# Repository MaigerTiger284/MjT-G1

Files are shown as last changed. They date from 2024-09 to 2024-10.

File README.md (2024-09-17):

โปรเจค MjT-G1 คือ เครื่องพิมพ์ 3 มิติ ที่ใช้โครงของ Davinci 1.0A เอามาพัฒนาต่อ ให้ใช้งานได้ดีขึ้น โปรเจดนี้ขึ้นเพื่อเป็นวิทยานิพนธ์เพื่อจบการศึกษมหาวิทยาลัยเทคโนโลยีราชมงคลพระนคร วิทยาเขตพระนครเหนือ

วัตถุประสงค์
- เพื่อศึกษาการทำงานเครื่องพิมพ์ 3 มิติ รุ่น Da Vinci 1.0A, Ender 5+, Anet et4+
- เพื่อศึกษาชุดคำสั่งของโปรแกรม klipper 
- เพื่อออกแบบระบบปฏิบัติการให้กับแท็บเล็ต Microsoft Surface RT ให้สามารถทำงานได้เหมาะสมกับเครื่องพิมพ์ 3 มิติ
- เพื่อออกแบบให้สามารถใช้เส้นพลาสติกของบริษัททั่วไปได้
- เพื่อออกแบบเพิ่มพื้นที่ฐานพิมพ์ให้มากขึ้น
- เพื่อออกแบบให้สามารถควบคุมการทำงานของเครื่องพิมพ์ 3 มิติ ผ่านสมาร์ทโฟน Androids หรือ IOS นอกสถานที่ได้ โดยใช้ระบบ Webserver Fluidd ที่เชื่อมต่อด้วย VPN (Virtual Private Network) ของ Zerotier One

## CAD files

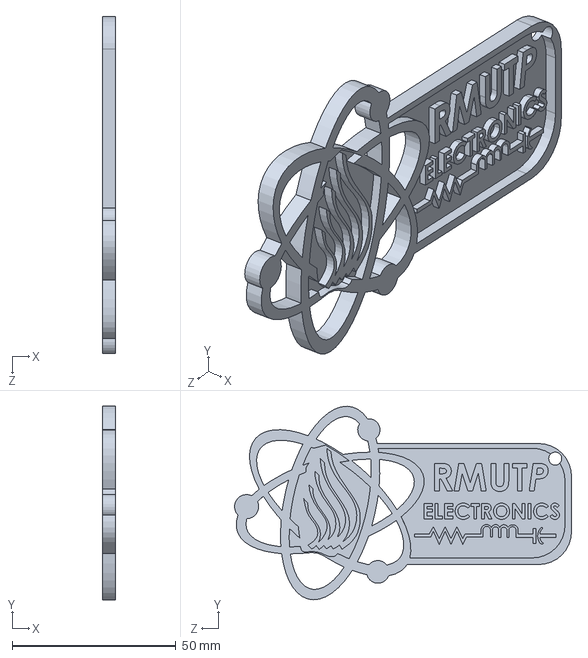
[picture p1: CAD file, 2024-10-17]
MjT-G1 Assembly 1/solidwork assembly part/key v2 EE.SLDPRT
4.00 x 59.2 x 103.0 mm

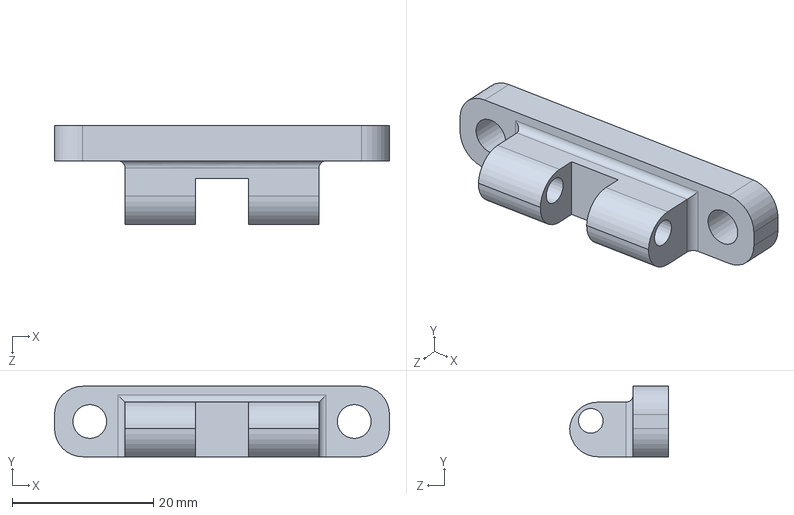
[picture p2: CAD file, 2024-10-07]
MjT-G1 Assembly 1/solidwork assembly part/webcam Stend.SLDPRT
47.5 x 10.0 x 14.0 mm

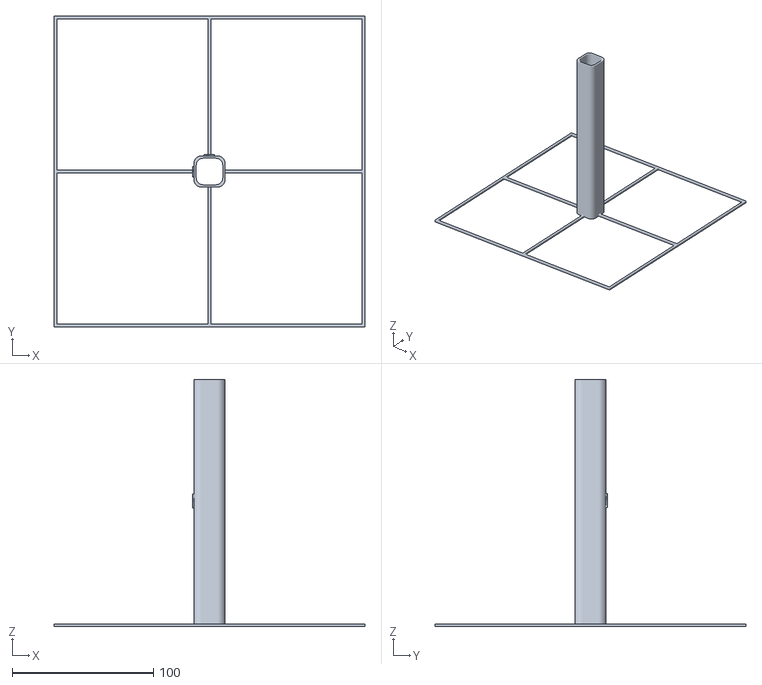
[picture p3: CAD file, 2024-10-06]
MjT-G1 Assembly 1/solidwork assembly part/bedtest 220x220.stl
220.0 x 220.0 x 175.0

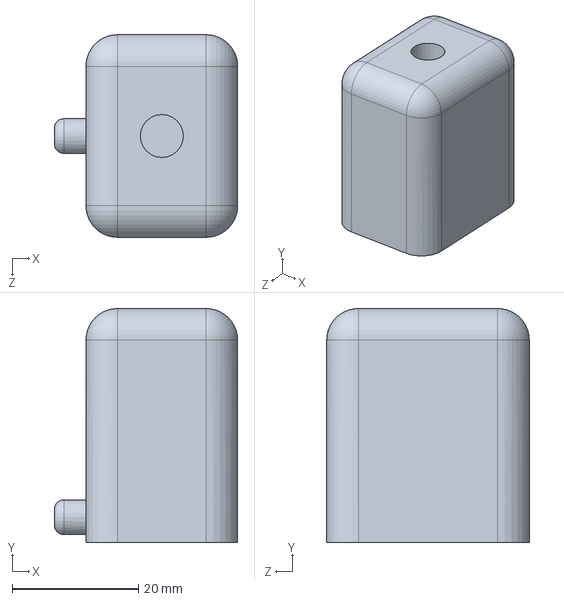
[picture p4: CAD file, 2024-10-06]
MjT-G1 Assembly 1/solidwork assembly part/ypully4.SLDPRT
29.0 x 37.0 x 32.0 mm

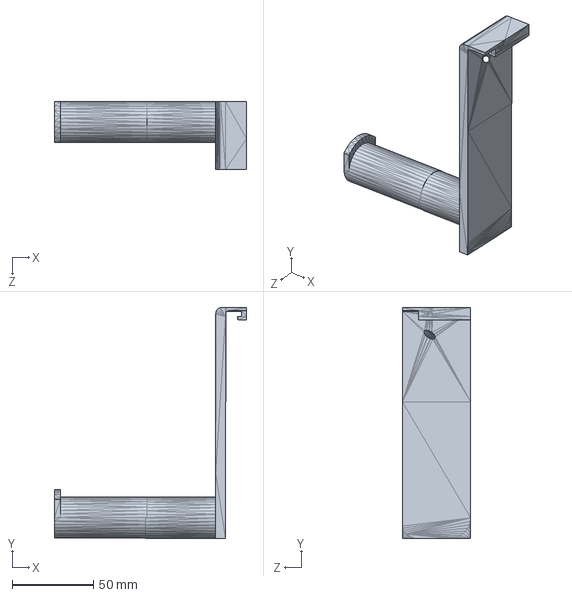
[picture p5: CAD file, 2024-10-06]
MjT-G1 Assembly 1/solidwork assembly part/xyz_davinci_10_pro_rear_spool_mount.SLDPRT
118.2 x 142.0 x 42.0 mm

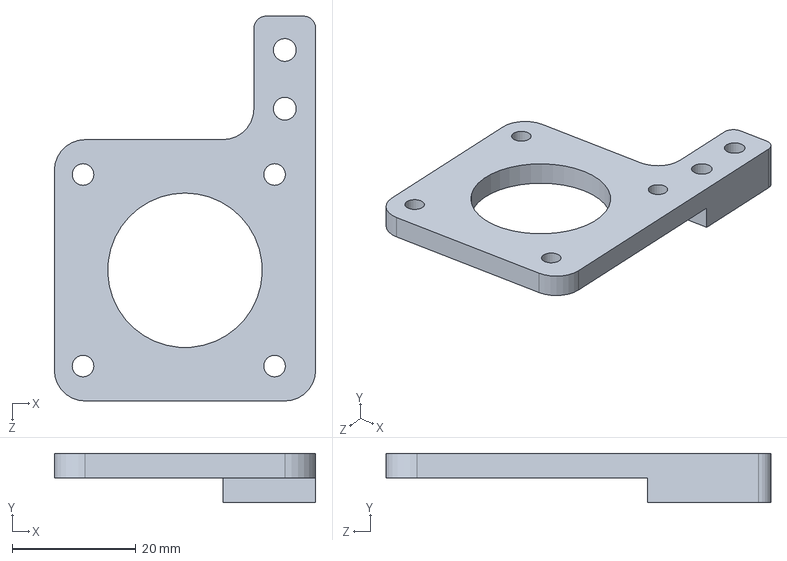
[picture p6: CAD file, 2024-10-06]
MjT-G1 Assembly 1/solidwork assembly part/yendstopand servo.SLDPRT
42.3 x 8.00 x 62.3 mm

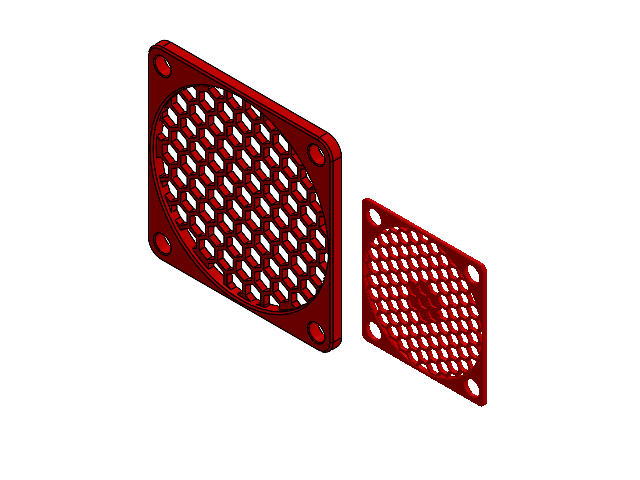
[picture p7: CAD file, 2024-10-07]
MjT-G1 Assembly 1/solidwork assembly part/Fan 40mm and 60mm.SLDASM
Honeycomb Fan Grill (Small Center)
60mm fan guard.step

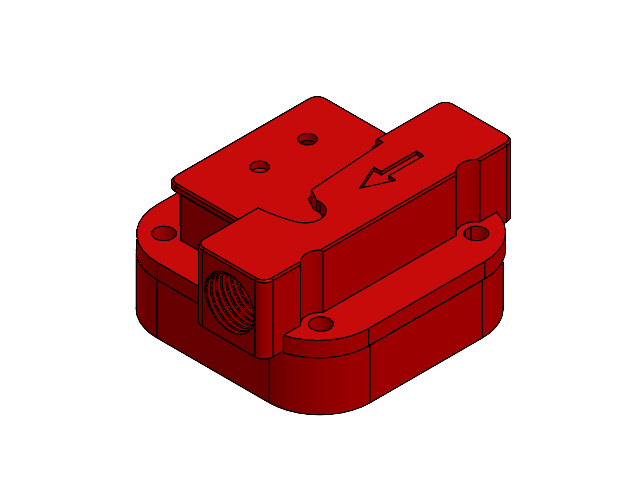
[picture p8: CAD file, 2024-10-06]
MjT-G1 Assembly 1/solidwork assembly part/E endstop runout.SLDASM
name17 back
RunoutSensor Body
runoutsensor-cover

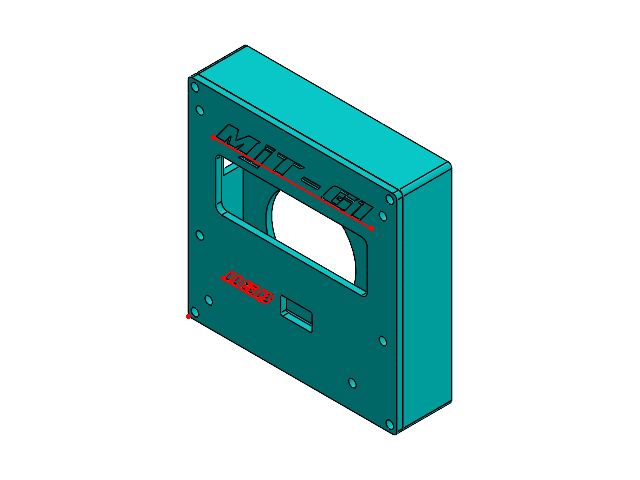
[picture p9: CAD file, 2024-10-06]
MjT-G1 Assembly 1/solidwork assembly part/LCD Box.SLDASM
cover4
lcd box

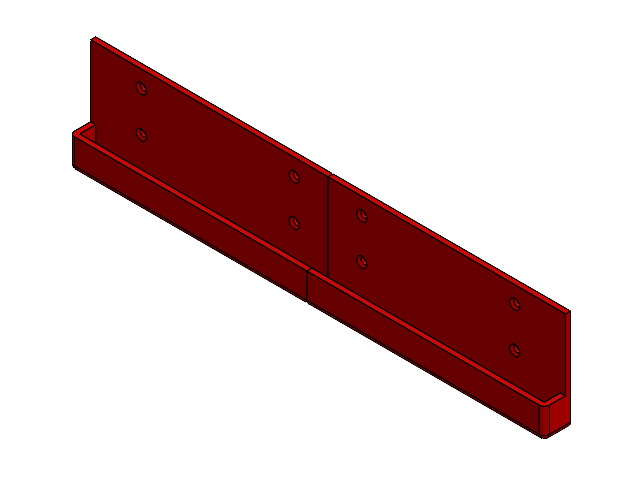
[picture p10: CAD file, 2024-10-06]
MjT-G1 Assembly 1/solidwork assembly part/Tablet RT support.SLDASM
table support l
table support r

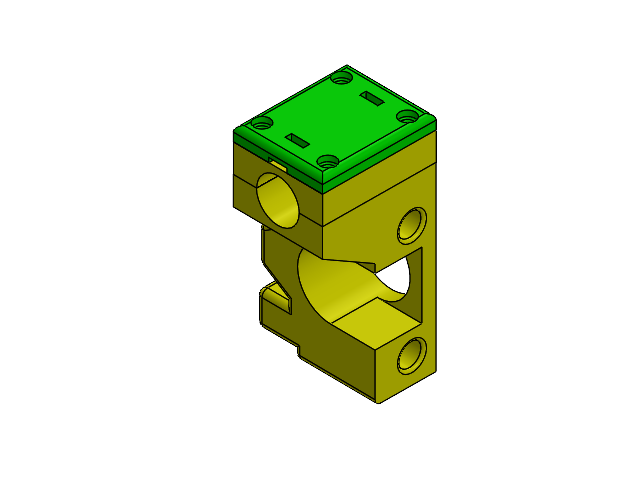
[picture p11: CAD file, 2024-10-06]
MjT-G1 Assembly 1/solidwork assembly part/X slide left.SLDASM
covertop
moto LL23
covertoptop

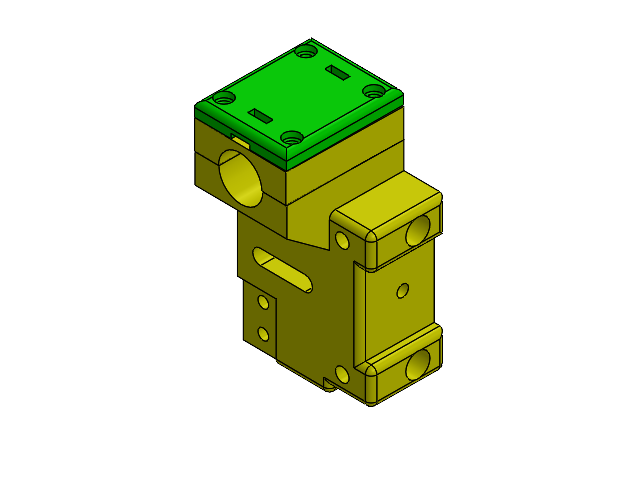
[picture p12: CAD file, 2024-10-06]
MjT-G1 Assembly 1/solidwork assembly part/X slide right.SLDASM
moto rr
covertop
covertoptop

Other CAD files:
MjT-G1 Assembly 1/solidwork assembly part/key v2 EE+Rmutp.STL

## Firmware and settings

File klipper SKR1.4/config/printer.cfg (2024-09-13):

[include timelapse.cfg]
[include fluidd_mcro.cfg]

[stepper_x]
step_pin: P2.2
dir_pin: !P2.6
enable_pin: !P2.1
full_steps_per_rotation: 200
microsteps: 16
rotation_distance: 40#39.6
endstop_pin: P1.29
position_endstop: 258
position_min: -33
position_max: 258
homing_speed: 100

[stepper_y]
step_pin: P0.19
dir_pin: P0.20
enable_pin: !P2.8
full_steps_per_rotation: 200
microsteps: 16
rotation_distance: 40#39.6
endstop_pin: P1.28
position_endstop: 224
position_min: -24
position_max: 224
homing_speed: 100

[stepper_z]
step_pin: P0.22
dir_pin: P2.11
enable_pin: !P0.21
microsteps: 16
full_steps_per_rotation: 200
rotation_distance: 8
endstop_pin: probe:z_virtual_endstop
#position_endstop: 0.0
position_min: -10
position_max: 185


[extruder]
step_pin: P2.13
dir_pin: !P0.11
enable_pin: !P2.12
microsteps: 16
gear_ratio: 3:1
rotation_distance: 22.74729191
nozzle_diameter: 0.400
filament_diameter: 1.750
pressure_advance: 0.04
max_extrude_cross_section: 50
max_extrude_only_distance: 700.00
heater_pin: P2.7
sensor_type: ATC Semitec 104NT-4-R025H42G #ATC Semitec 104GT-2
sensor_pin: P0.24
#control: pid
#pid_Kp: 22.2
#pid_Ki: 1.08
#pid_Kd: 114
min_temp: 0
max_temp: 290

[temperature_sensor CPU]
sensor_type: temperature_host
sensor_path: /sys/class/thermal/thermal_zone0/temp

[fan]
pin: P2.3

[heater_fan heatbreak_cooling_fan]
pin: P2.4
heater_temp: 80.0

[mcu]
serial: /dev/serial/by-id/usb-1a86_USB_Serial-if00-port0
baud: 250000
restart_method: command


#[mcu arduino]
#serial: /dev/serial/by-id/usb-Arduino__www.arduino.cc__0042_85633343439351209241-if00
#baud: 250000
#restart_method: command

#[adxl345]
#cs_pin: arduino:PA0
#spi_software_sclk_pin: arduino:PB1
#spi_software_mosi_pin: arduino:PB2
#spi_software_miso_pin: arduino:PB3

#[resonance_tester]
#accel_chip: adxl345
##probe_points:
#  110,110,20

[printer]
kinematics: cartesian
max_velocity: 500
max_accel: 5000
max_z_velocity: 5

[safe_z_home]
home_xy_position: 110.00,120
speed: 150
z_hop: 5
z_hop_speed: 10

[input_shaper]
shaper_type_x = 2hump_ei
shaper_freq_x = 49.4 
shaper_type_y = ei
shaper_freq_y = 30.8

[bltouch]
sensor_pin: P0.10
control_pin: P2.0
x_offset: 0
y_offset: 27
#z_offset: 0


[heater_bed]
heater_pin: P2.5
sensor_type: EPCOS 100K B57560G104F #Generic 3950#EPCOS 100K B57560G104F
sensor_pin: P0.25
#control: pid
#pid_Kp: 54.027
#pid_Ki: 0.770
#pid_Kd: 948.182
min_temp: 0
max_temp: 130

[screws_tilt_adjust]
screw1: 32.00, 35
screw2: 200.00, 35
screw3: 200.00, 230.00
screw4: 32.00, 230.00
speed: 150
horizontal_move_z: 5
screw_thread: CW-M3

[tmc2209 stepper_x]
uart_pin: P1.10
run_current: 0.707
hold_current: 0.300
interpolate: False
stealthchop_threshold: 500

[tmc2209 stepper_y]
uart_pin: P1.9
run_current: 0.707
hold_current: 0.300
interpolate: False
stealthchop_threshold: 500

[tmc2209 stepper_z]
uart_pin: P1.8
run_current: 0.800
hold_current: 0.450
interpolate: False
stealthchop_threshold: 500

[tmc2209 extruder]
uart_pin: P1.4
run_current: 0.650
hold_current: 0.300
interpolate: False

[bed_mesh]
speed: 150
horizontal_move_z: 5
mesh_min: 7,7
mesh_max: 220,220
probe_count: 5,5
algorithm: bicubic
fade_start: 1
fade_end: 10
fade_target: 0



[output_pin caselight]
pin: P1.24
value: 1
shutdown_value: 1

[force_move]
enable_force_move: true

########################################
# EXP1 / EXP2 (display) pins
########################################
[board_pins]
aliases:
    # EXP1 header
    EXP1_1=P1.30, EXP1_3=P1.18, EXP1_5=P1.20, EXP1_7=P1.22, EXP1_9=<GND>,
    EXP1_2=P0.28, EXP1_4=P1.19, EXP1_6=P1.21, EXP1_8=P1.23, EXP1_10=<5V>,
    # EXP2 header
    EXP2_1=P0.17, EXP2_3=P3.26, EXP2_5=P3.25, EXP2_7=P1.31, EXP2_9=<GND>,
    EXP2_2=P0.15, EXP2_4=P0.16, EXP2_6=P0.18, EXP2_8=<RST>, EXP2_10=<NC>
 
[display]
lcd_type: hd44780
display_group: _default_20x4
rs_pin: EXP1_7
e_pin: EXP1_5
d4_pin: EXP1_3
d5_pin: EXP1_8
d6_pin: EXP1_2
d7_pin: EXP1_6


[virtual_sdcard]
path: /home/pi/printer_data/gcodes

[delayed_gcode bed_mesh_init]
initial_duration: .01
gcode:
  BED_MESH_PROFILE LOAD=default

[filament_switch_sensor filament_sensor]
switch_pin: P1.26 # MAT_DET
pause_on_runout: True

#*# <---------------------- SAVE_CONFIG ---------------------->
#*# DO NOT EDIT THIS BLOCK OR BELOW. The contents are auto-generated.
#*#
#*# [heater_bed]
#*# control = pid
#*# pid_kp = 76.487
#*# pid_ki = 1.569
#*# pid_kd = 932.184
#*#
#*# [extruder]
#*# control = pid
#*# pid_kp = 25.499
#*# pid_ki = 1.241
#*# pid_kd = 131.000
#*#
#*# [bltouch]
#*# z_offset = 1.290
#*#
#*# [bed_mesh default]
#*# version = 1
#*# points =
#*# 	-0.090000, -0.117500, -0.080000, -0.017500, -0.052500
#*# 	0.055000, -0.035000, -0.035000, 0.035000, 0.045000
#*# 	0.175000, 0.035000, -0.005000, 0.055000, 0.090000
#*# 	0.162500, 0.070000, 0.000000, 0.060000, 0.085000
#*# 	0.140000, 0.015000, -0.025000, 0.017500, 0.052500
#*# x_count = 5
#*# y_count = 5
#*# mesh_x_pps = 2
#*# mesh_y_pps = 2
#*# algo = bicubic
#*# tension = 0.2
#*# min_x = 7.0
#*# max_x = 220.0
#*# min_y = 7.0
#*# max_y = 220.0

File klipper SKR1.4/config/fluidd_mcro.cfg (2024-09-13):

## Client klipper macro definitions
##
## Copyright (C) 2022 Alex Zellner <alexander.zellner@googlemail.com>
##
## This file may be distributed under the terms of the GNU GPLv3 license
##
## !!! This file is read-only. Maybe the used editor indicates that. !!!
##
## Customization:
##   1) copy the gcode_macro _CLIENT_VARIABLE (see below) to your printer.cfg
##   2) remove the comment mark (#) from all lines
##   3) change any value in there to your needs
##
## Use the PAUSE macro direct in your M600:
##  e.g. with a different park position front left and a minimal height of 50
##    [gcode_macro M600]
##    description: Filament change
##    gcode: PAUSE X=10 Y=10 Z_MIN=50
##  Z_MIN will park the toolhead at a minimum of 50 mm above to bed to make it easier for you to swap filament.
##
## Client variable macro for your printer.cfg
#[gcode_macro _CLIENT_VARIABLE]
#variable_use_custom_pos   : False ; use custom park coordinates for x,y [True/False]
#variable_custom_park_x    : 0.0   ; custom x position; value must be within your defined min and max of X
#variable_custom_park_y    : 0.0   ; custom y position; value must be within your defined min and max of Y
#variable_custom_park_dz   : 2.0   ; custom dz value; the value in mm to lift the nozzle when move to park position
#variable_retract          : 1.0   ; the value to retract while PAUSE
#variable_cancel_retract   : 5.0   ; the value to retract while CANCEL_PRINT
#variable_speed_retract    : 35.0  ; retract speed in mm/s
#variable_unretract        : 1.0   ; the value to unretract while RESUME
#variable_speed_unretract  : 35.0  ; unretract speed in mm/s
#variable_speed_hop        : 15.0  ; z move speed in mm/s
#variable_speed_move       : 100.0 ; move speed in mm/s
#variable_park_at_cancel   : False ; allow to move the toolhead to park while execute CANCEL_PRINT [True/False]
#variable_park_at_cancel_x : None  ; different park position during CANCEL_PRINT [None/Position as Float]; park_at_cancel must be True
#variable_park_at_cancel_y : None  ; different park position during CANCEL_PRINT [None/Position as Float]; park_at_cancel must be True
## !!! Caution [firmware_retraction] must be defined in the printer.cfg if you set use_fw_retract: True !!!
#variable_use_fw_retract   : False ; use fw_retraction instead of the manual version [True/False]
#variable_idle_timeout     : 0     ; time in sec until idle_timeout kicks in. Value 0 means that no value will be set or restored
#variable_runout_sensor    : ""    ; If a sensor is defined, it will be used to cancel the execution of RESUME in case no filament is detected.
##                                   Specify the config name of the runout sensor e.g "filament_switch_sensor runout". Hint use the same as in your printer.cfg
## !!! Custom macros, please use with care and review the section of the corresponding macro.
## These macros are for simple operations like setting a status LED. Please make sure your macro does not interfere with the basic macro functions.
## Only  single line commands are supported, please create a macro if you need more than one command.
#variable_user_pause_macro : ""    ; Everything inside the "" will be executed after the klipper base pause (PAUSE_BASE) function
#variable_user_resume_macro: ""    ; Everything inside the "" will be executed before the klipper base resume (RESUME_BASE) function
#variable_user_cancel_macro: ""    ; Everything inside the "" will be executed before the klipper base cancel (CANCEL_PRINT_BASE) function
#gcode:

[virtual_sdcard]
path: ~/printer_data/gcodes
on_error_gcode: CANCEL_PRINT

[pause_resume]
#recover_velocity: 50.
#   When capture/restore is enabled, the speed at which to return to
#   the captured position (in mm/s). Default is 50.0 mm/s.

[display_status]

[respond]

[gcode_macro lights_toggle]
gcode:
    {% if printer["output_pin caselight"].value == 1 %}
        SET_PIN PIN=caselight VALUE=0
    {% else %}
        SET_PIN PIN=caselight VALUE=1
    {% endif %}
[gcode_macro LED_OFF]
gcode:
    SET_PIN PIN=caselight VALUE=0

[gcode_macro LED_ON]
gcode:
    SET_PIN PIN=caselight VALUE=1

[gcode_macro CANCEL_PRINT]
description: Cancel the actual running print
rename_existing: CANCEL_PRINT_BASE
gcode:
  TURN_OFF_HEATERS
  {% if "xyz" in printer.toolhead.homed_axes %}
    G91
    G1 Z4.5 F300
    G90
  {% else %}
    {action_respond_info("Printer not homed")}
  {% endif %}
    G28 X Y
  {% set y_park = printer.toolhead.axis_maximum.y|float - 5.0 %}
    G1 Y{y_park} F2000
    M84
  CANCEL_PRINT_BASE

[gcode_macro PAUSE]
description: Pause the actual running print
rename_existing: PAUSE_BASE
gcode:
  ##### get user parameters or use default #####
  {% set client = printer['gcode_macro _CLIENT_VARIABLE'] | default({}) %}
  {% set idle_timeout = client.idle_timeout | default(0) %}
  {% set temp = printer[printer.toolhead.extruder].target if printer.toolhead.extruder != '' else 0 %}
  {% set restore = False if printer.toolhead.extruder == ''
              else True  if params.RESTORE | default(1) | int == 1 else False %}
  ##### end of definitions #####
  SET_GCODE_VARIABLE MACRO=RESUME VARIABLE=last_extruder_temp VALUE="{{'restore': restore, 'temp': temp}}"
  # set a new idle_timeout value
  {% if idle_timeout > 0 %}
    SET_GCODE_VARIABLE MACRO=RESUME VARIABLE=restore_idle_timeout VALUE={printer.configfile.settings.idle_timeout.timeout}
    SET_IDLE_TIMEOUT TIMEOUT={idle_timeout}
  {% endif %}
  PAUSE_BASE
  {client.user_pause_macro | default("")}
  _TOOLHEAD_PARK_PAUSE_CANCEL {rawparams}
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

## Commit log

2024-10-06 add part slide
    [X slide left.SLDASM, X slide right.SLDASM]
2024-10-06 add rt support
    [Tablet RT support.SLDASM]
2024-10-06 add lcd
    [LCD Box.SLDASM]
2024-10-06 add lcd box
    [LCD Box.SLDASM, yendstopand servo.SLDPRT]
2024-10-06 add stend filement
    [xyz_davinci_10_pro_rear_spool_mount.SLDPRT]
2024-10-06 E endstop
    [E endstop runout.SLDASM]
2024-10-06 Y pully
    [ypully4.SLDPRT]
2024-10-06 Add fan cover
    [Fan 40mm and 60mm.SLDASM]
2024-10-06 Create bed test 220x220.STL
    [bed test 220x220.STL]
2024-10-06 add bed test
    [bed test 220x220.STL, bedtest 220x220.stl]
2024-10-07 add webcam stand
    [Fan 40mm and 60mm.SLDASM, webcam Stend.SLDPRT]
2024-10-17 Create key v2 EE+Rmutp.STL
    [key v2 EE+Rmutp.STL]
2024-10-17 Create key v2 EE.SLDPRT
    [key v2 EE.SLDPRT]
2025-03-11 add nw
    [fluidd.cfg, printer-20240407_112924.cfg, printer-20240407_114120.cfg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]
